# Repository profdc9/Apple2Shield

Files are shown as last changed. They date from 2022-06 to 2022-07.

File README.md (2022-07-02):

# Apple II Arduino Shield

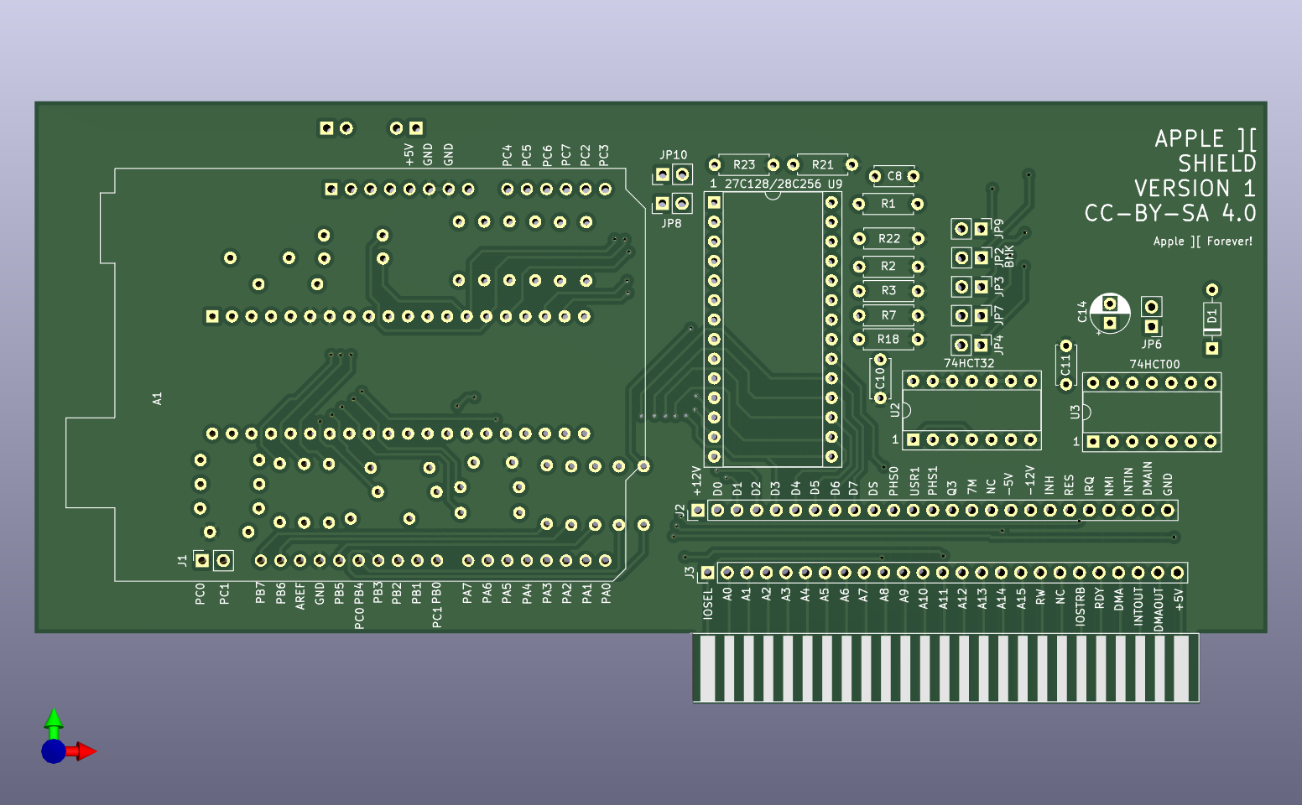
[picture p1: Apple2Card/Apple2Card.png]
Apple2Card


This is a simple card to interface an Apple II bus to an Arduino Uno or an Arduino Shield using the 82C55 interface.  If stackable headers are soldered into the interface card, an Arduino Uno may be mounted on the back of the card, and shields may be stacked on the front of the card.  This way an Arduino Shield may be used without an Arduino by the card by bit-banging it with the 82C55, or an Arduino may control the card.  There is also a ROM on the board that can contain your own firmware if you desire, and the hardware to flash it.  The design is derived from another project http://www.github.com/profdc9/Apple2Card

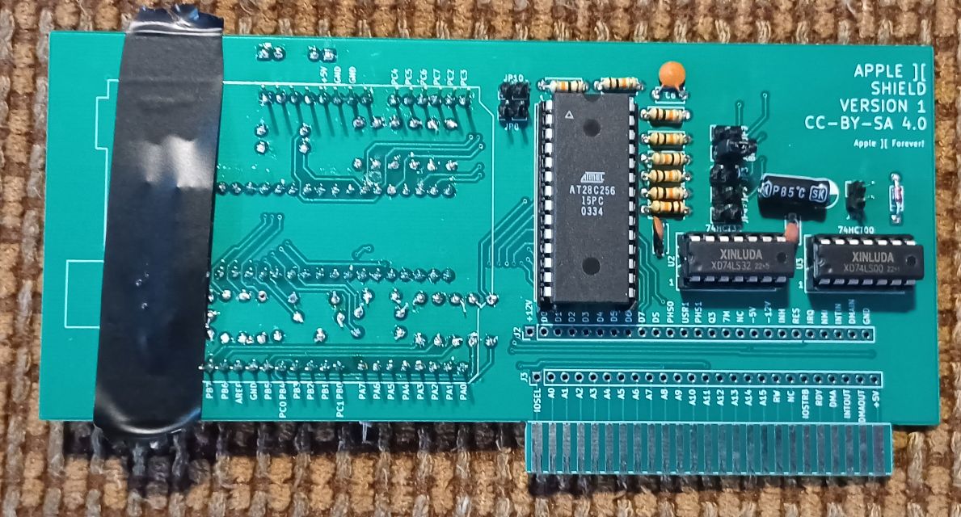
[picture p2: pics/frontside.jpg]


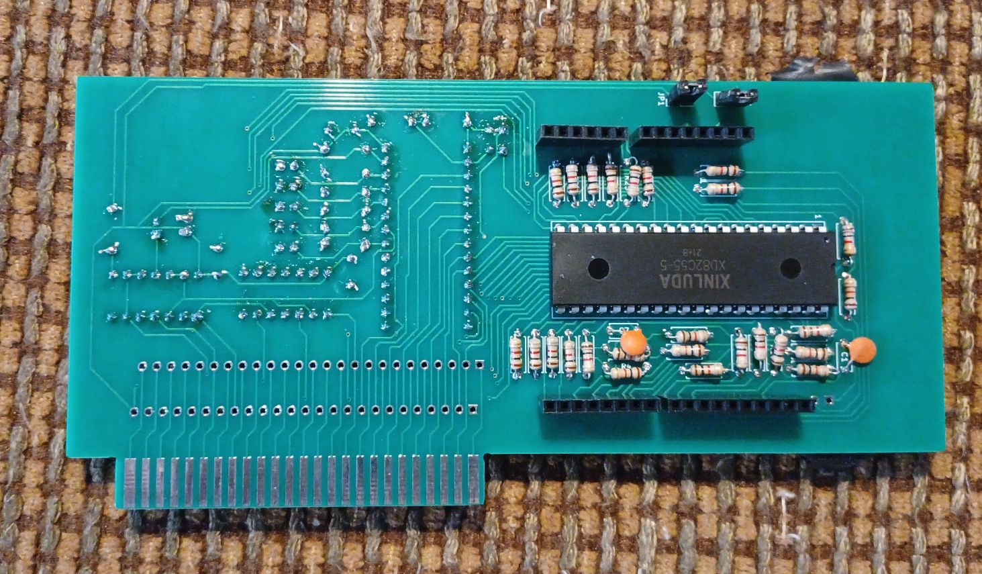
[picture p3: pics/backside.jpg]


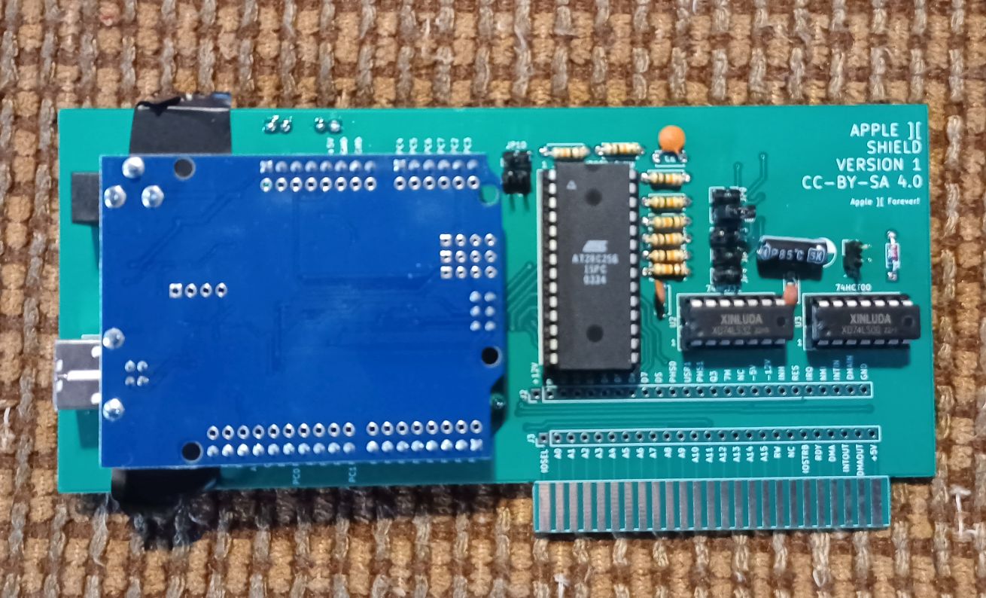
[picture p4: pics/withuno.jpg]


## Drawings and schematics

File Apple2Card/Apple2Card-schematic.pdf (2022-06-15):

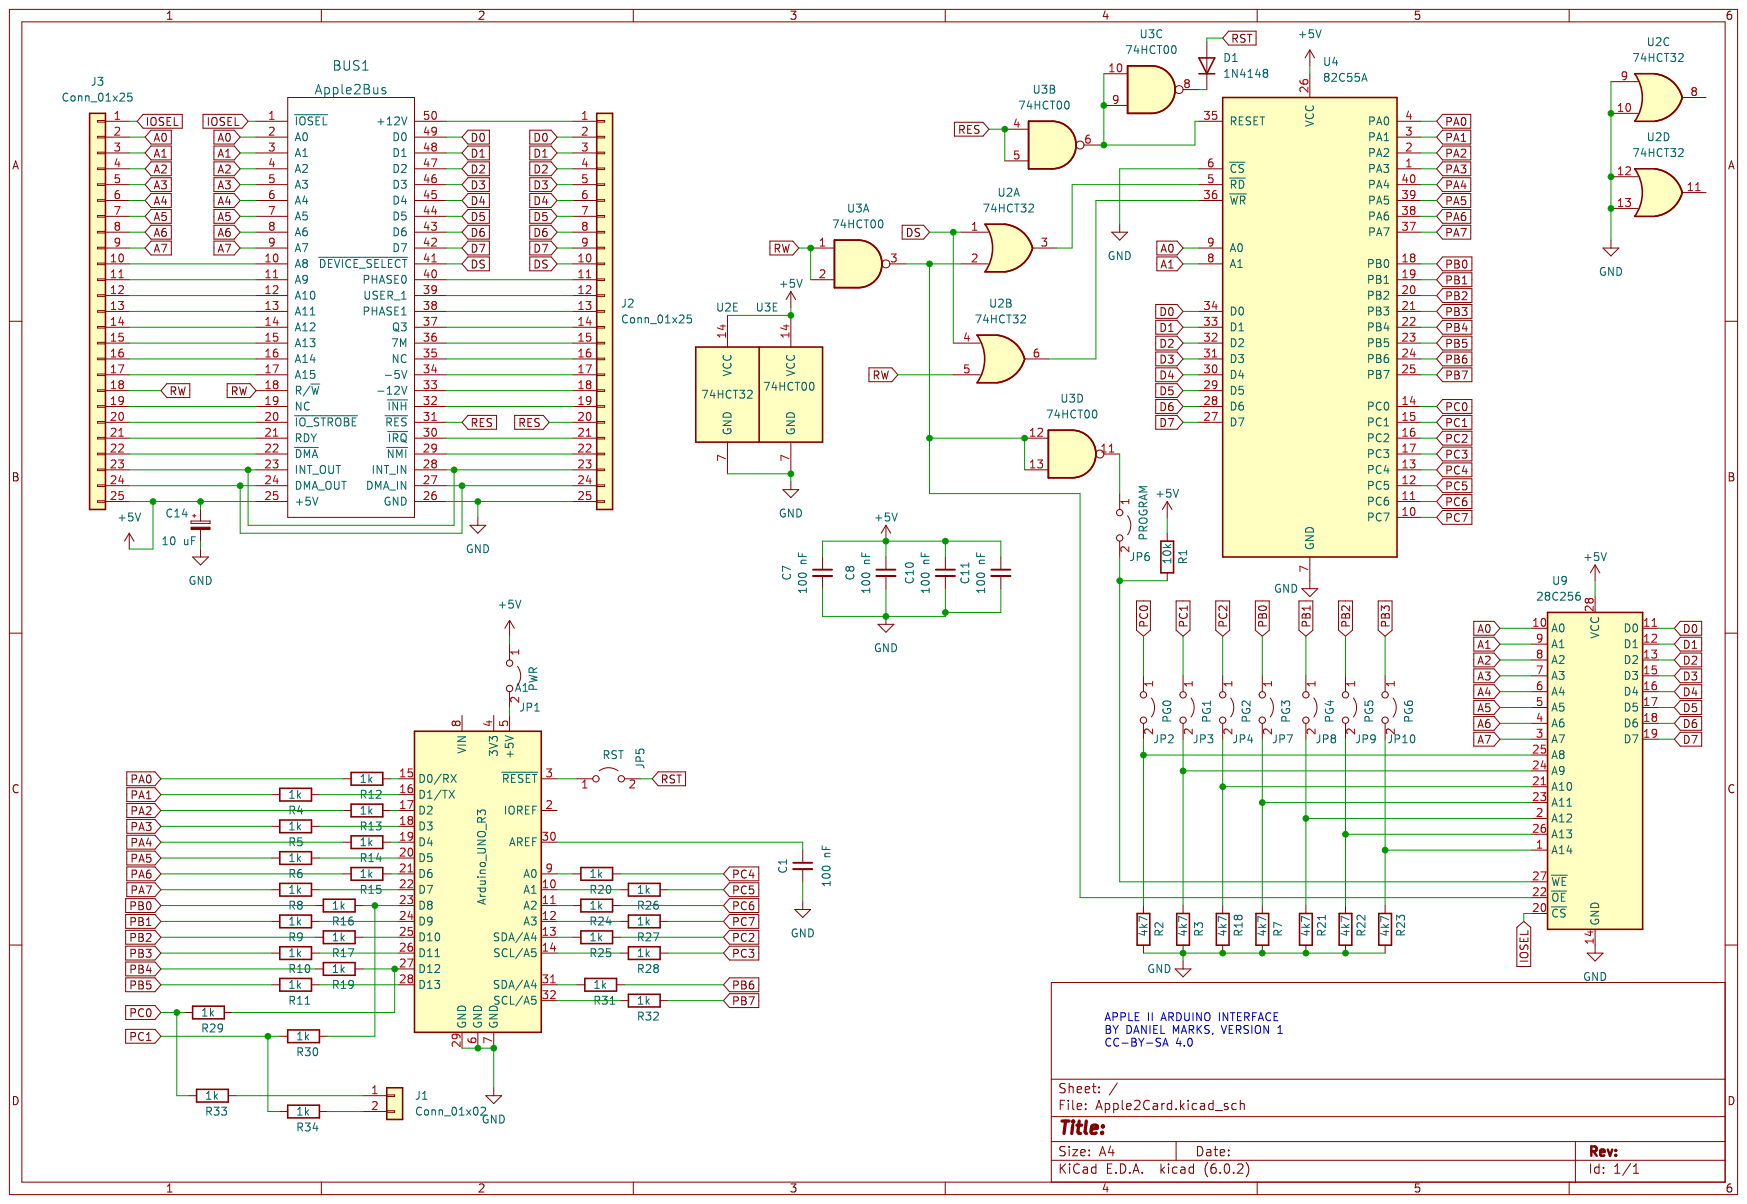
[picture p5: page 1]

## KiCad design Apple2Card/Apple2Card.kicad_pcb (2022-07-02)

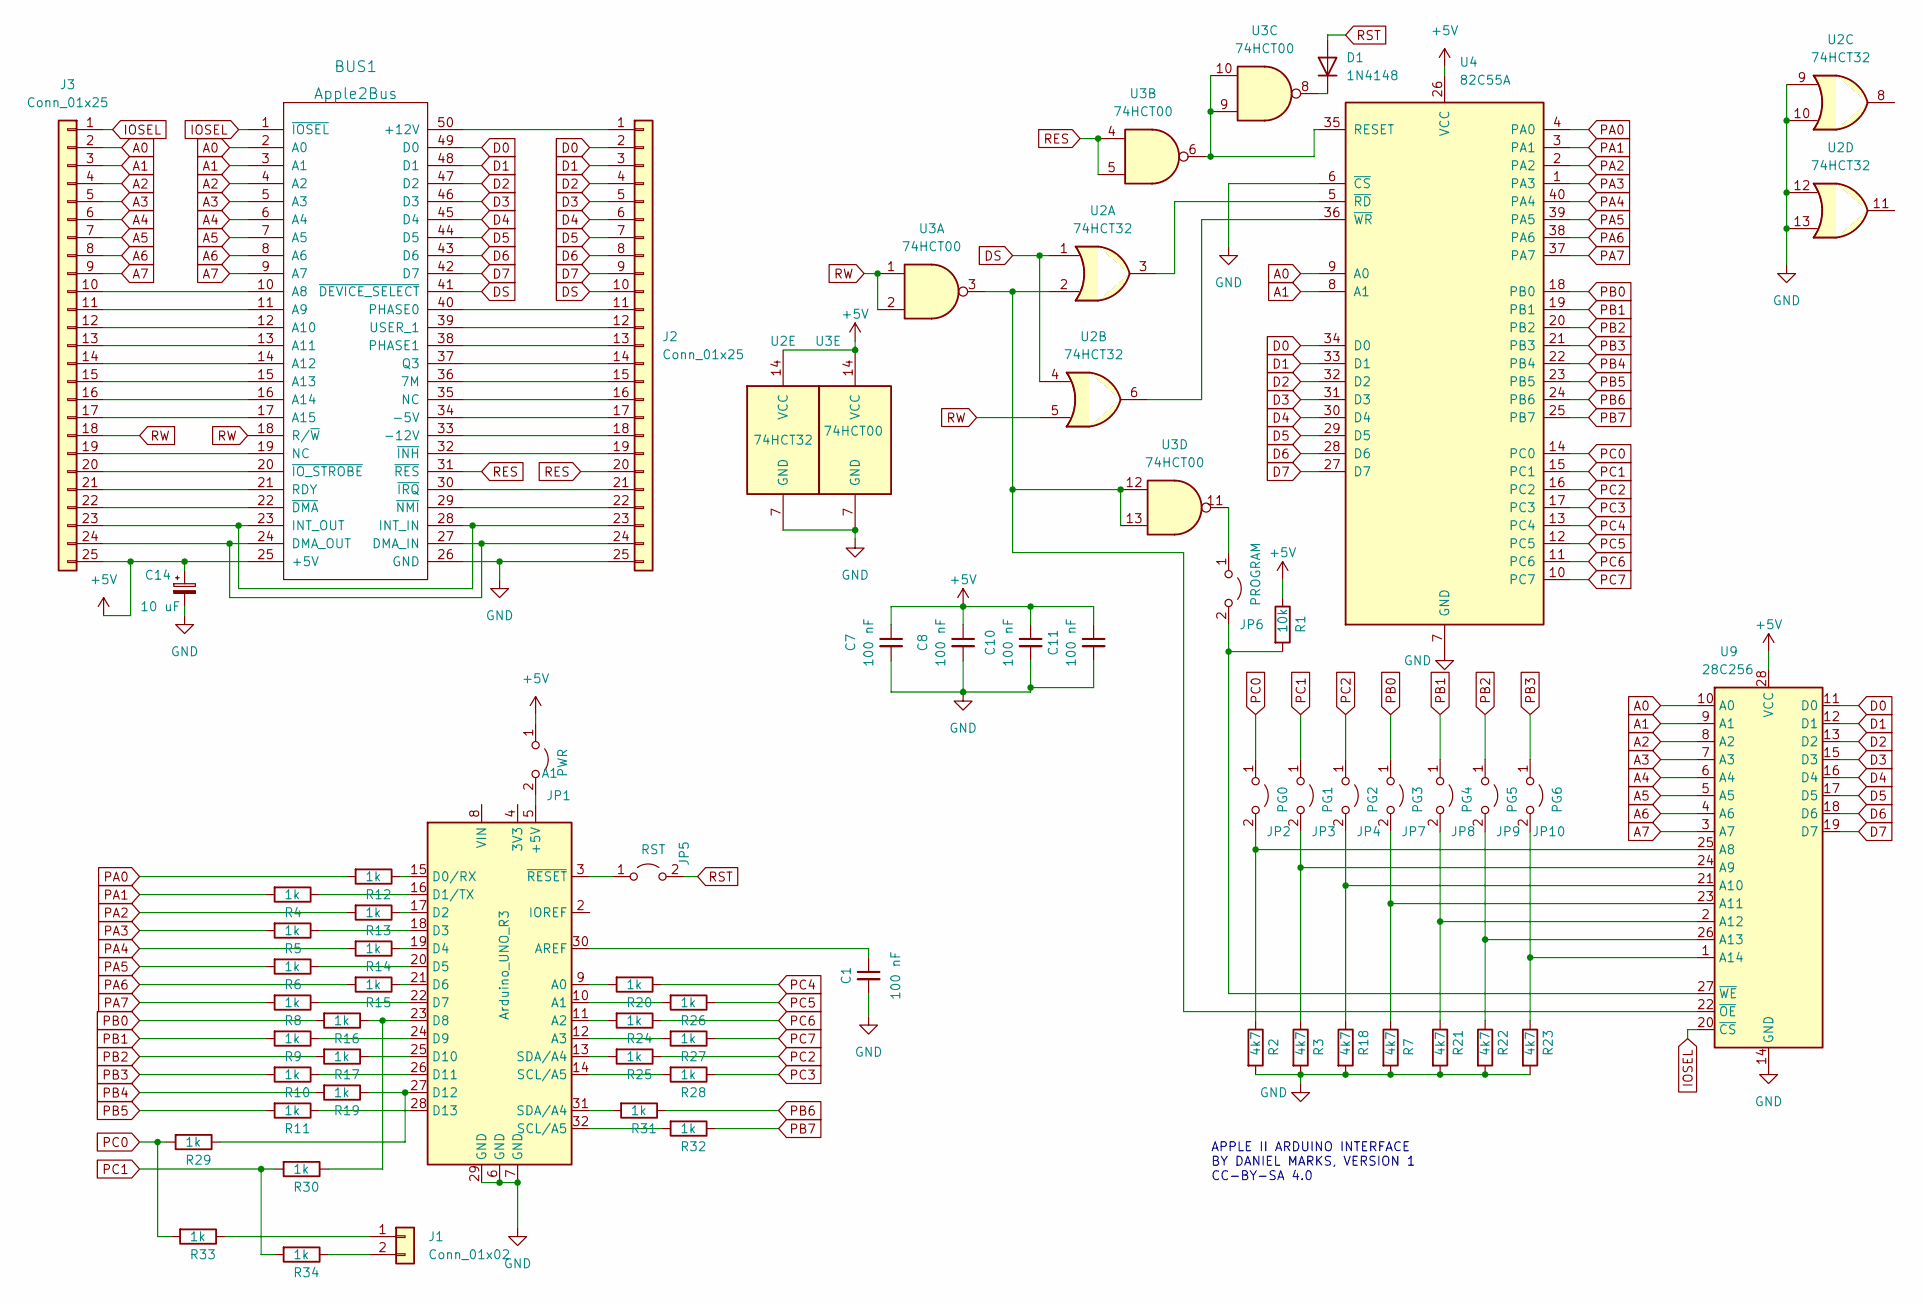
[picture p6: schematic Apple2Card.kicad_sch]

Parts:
A1: Arduino_UNO_R3
BUS1: Apple2Bus; Apple2Slot
C1, C7, C8, C10, C11: 100 nF; C_Disc_D5.0mm_W2.5mm_P5.00mm
C14: 10 uF; CP_Radial_D5.0mm_P2.50mm
D1: 1N4148; D_DO-35_SOD27_P7.62mm_Horizontal
J1: Conn_01x02; PinSocket_1x02_P2.54mm_Vertical
J2, J3: Conn_01x25; PinHeader_1x25_P2.54mm_Vertical
JP1: PWR; PinHeader_1x02_P2.54mm_Vertical
JP2: PG0; PinHeader_1x02_P2.54mm_Vertical
JP3: PG1; PinHeader_1x02_P2.54mm_Vertical
JP4: PG2; PinHeader_1x02_P2.54mm_Vertical
JP5: RST; PinHeader_1x02_P2.54mm_Vertical
JP6: PROGRAM; PinHeader_1x02_P2.54mm_Vertical
JP7: PG3; PinHeader_1x02_P2.54mm_Vertical
JP8: PG4; PinHeader_1x02_P2.54mm_Vertical
JP9: PG5; PinHeader_1x02_P2.54mm_Vertical
JP10: PG6; PinHeader_1x02_P2.54mm_Vertical
R1: 10k; R_Axial_DIN0207_L6.3mm_D2.5mm_P7.62mm_Horizontal
R2, R3, R7, R18, R21, R22, R23: 4k7; R_Axial_DIN0207_L6.3mm_D2.5mm_P7.62mm_Horizontal
R4, R5, R6, R8, R9, R10, R11, R12, R13, R14, R15, R16, R17, R19, R20, R24, R25, R26, R27, R28, R29, R30, R31, R32, R33, R34: 1k; R_Axial_DIN0207_L6.3mm_D2.5mm_P7.62mm_Horizontal
U2: 74HCT32; DIP-14_W7.62mm_Socket
U3: 74HCT00; DIP-14_W7.62mm_Socket
U4: 82C55A; DIP-40_W15.24mm_Socket
U9: 28C256; DIP-28_W15.24mm_Socket

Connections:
+5V: BUS1.25 (+5V), C7.1, C8.1, C10.1, C11.1, C14.1, J3.25, JP1.1 (A), R1.1, U2.14 (VCC), U3.14 (VCC), U4.26 (VCC), U9.28 (VCC)
A0: BUS1.2 (A0), J3.2, U4.9 (A0), U9.10 (A0)
A1: BUS1.3 (A1), J3.3, U4.8 (A1), U9.9 (A1)
A2: BUS1.4 (A2), J3.4, U9.8 (A2)
A3: BUS1.5 (A3), J3.5, U9.7 (A3)
A4: BUS1.6 (A4), J3.6, U9.6 (A4)
A5: BUS1.7 (A5), J3.7, U9.5 (A5)
A6: BUS1.8 (A6), J3.8, U9.4 (A6)
A7: BUS1.9 (A7), J3.9, U9.3 (A7)
D0: BUS1.49 (D0), J2.2, U4.34 (D0), U9.11 (D0)
D1: BUS1.48 (D1), J2.3, U4.33 (D1), U9.12 (D1)
D2: BUS1.47 (D2), J2.4, U4.32 (D2), U9.13 (D2)
D3: BUS1.46 (D3), J2.5, U4.31 (D3), U9.15 (D3)
D4: BUS1.45 (D4), J2.6, U4.30 (D4), U9.16 (D4)
D5: BUS1.44 (D5), J2.7, U4.29 (D5), U9.17 (D5)
D6: BUS1.43 (D6), J2.8, U4.28 (D6), U9.18 (D6)
D7: BUS1.42 (D7), J2.9, U4.27 (D7), U9.19 (D7)
DS: BUS1.41 (~DEVICE_SELECT), J2.10, U2.1, U2.4
GND: A1.6 (GND), A1.7 (GND), A1.29 (GND), BUS1.26 (GND), C1.2, C7.2, C8.2, C10.2, C11.2, C14.2, J2.25, R2.2, R3.2, R7.2, R18.2, R21.2, R22.2, R23.2, U2.7 (GND), U2.9, U2.10, U2.12, U2.13, U3.7 (GND), U4.6 (~CS), U4.7 (GND), U9.14 (GND)
IOSEL: BUS1.1 (~IOSEL), J3.1, U9.20 (~CS)
unnamed: A1.3 (~RESET), JP5.1 (A)
unnamed: A1.5 (+5V), JP1.2 (B)
unnamed: A1.9 (A0), R20.2
unnamed: A1.10 (A1), R26.2
unnamed: A1.11 (A2), R24.2
unnamed: A1.12 (A3), R27.2
unnamed: A1.13 (SDA/A4), R25.2
unnamed: A1.14 (SCL/A5), R28.2
unnamed: A1.15 (D0/RX), R12.1
unnamed: A1.16 (D1/TX), R4.1
unnamed: A1.17 (D2), R13.1
unnamed: A1.18 (D3), R5.1
unnamed: A1.19 (D4), R14.1
unnamed: A1.20 (D5), R6.1
unnamed: A1.21 (D6), R15.1
unnamed: A1.22 (D7), R8.1
unnamed: A1.23 (D8), R16.1, R30.1
unnamed: A1.24 (D9), R9.1
unnamed: A1.25 (D10), R17.1
unnamed: A1.26 (D11), R10.1
unnamed: A1.27 (D12), R19.1, R29.1
unnamed: A1.28 (D13), R11.1
unnamed: A1.30 (AREF), C1.1
unnamed: A1.31 (SDA/A4), R31.2
unnamed: A1.32 (SCL/A5), R32.2
unnamed: BUS1.10 (A8), J3.10
unnamed: BUS1.11 (A9), J3.11
unnamed: BUS1.12 (A10), J3.12
unnamed: BUS1.13 (A11), J3.13
unnamed: BUS1.14 (A12), J3.14
unnamed: BUS1.15 (A13), J3.15
unnamed: BUS1.16 (A14), J3.16
unnamed: BUS1.17 (A15), J3.17
unnamed: BUS1.19 (NC), J3.19
unnamed: BUS1.20 (~IO_STROBE), J3.20
unnamed: BUS1.21 (RDY), J3.21
unnamed: BUS1.22 (~DMA), J3.22
unnamed: BUS1.23 (INT_OUT), BUS1.28 (INT_IN), J2.23, J3.23
unnamed: BUS1.24 (DMA_OUT), BUS1.27 (DMA_IN), J2.24, J3.24
unnamed: BUS1.29 (~NMI), J2.22
unnamed: BUS1.30 (~IRQ), J2.21
unnamed: BUS1.32 (~INH), J2.19
unnamed: BUS1.33 (-12V), J2.18
unnamed: BUS1.34 (-5V), J2.17
unnamed: BUS1.35 (NC), J2.16
unnamed: BUS1.36 (7M), J2.15
unnamed: BUS1.37 (Q3), J2.14
unnamed: BUS1.38 (PHASE1), J2.13
unnamed: BUS1.39 (USER_1), J2.12
unnamed: BUS1.40 (PHASE0), J2.11
unnamed: BUS1.50 (+12V), J2.1
unnamed: D1.1 (K), U3.8
unnamed: J1.1, R33.1
unnamed: J1.2, R34.1
unnamed: JP2.2 (B), R2.1, U9.25 (A8)
unnamed: JP3.2 (B), R3.1, U9.24 (A9)
unnamed: JP4.2 (B), R18.1, U9.21 (A10)
unnamed: JP6.1 (A), U3.11
unnamed: JP6.2 (B), R1.2, U9.27 (~WE)
unnamed: JP7.2 (B), R7.1, U9.23 (A11)
unnamed: JP8.2 (B), R21.1, U9.2 (A12)
unnamed: JP9.2 (B), R22.1, U9.26 (A13)
unnamed: JP10.2 (B), R23.1, U9.1 (A14)
unnamed: U2.2, U3.3, U3.12, U3.13, U9.22 (~OE)
unnamed: U2.3, U4.5 (~RD)
unnamed: U2.6, U4.36 (~WR)
unnamed: U3.6, U3.9, U3.10, U4.35 (RESET)
PA0: R12.2, U4.4 (PA0)
PA1: R4.2, U4.3 (PA1)
PA2: R13.2, U4.2 (PA2)
PA3: R5.2, U4.1 (PA3)
PA4: R14.2, U4.40 (PA4)
PA5: R6.2, U4.39 (PA5)
PA6: R15.2, U4.38 (PA6)
PA7: R8.2, U4.37 (PA7)
PB0: JP7.1 (A), R16.2, U4.18 (PB0)
PB1: JP8.1 (A), R9.2, U4.19 (PB1)
PB2: JP9.1 (A), R17.2, U4.20 (PB2)
PB3: JP10.1 (A), R10.2, U4.21 (PB3)
PB4: R19.2, U4.22 (PB4)
PB5: R11.2, U4.23 (PB5)
PB6: R31.1, U4.24 (PB6)
PB7: R32.1, U4.25 (PB7)
PC0: JP2.1 (A), R29.2, R33.2, U4.14 (PC0)
PC1: JP3.1 (A), R30.2, R34.2, U4.15 (PC1)
PC2: JP4.1 (A), R25.1, U4.16 (PC2)
PC3: R28.1, U4.17 (PC3)
PC4: R20.1, U4.13 (PC4)
PC5: R26.1, U4.12 (PC5)
PC6: R24.1, U4.11 (PC6)
PC7: R27.1, U4.10 (PC7)
RES: BUS1.31 (~RES), J2.20, U3.4, U3.5
RST: D1.2 (A), JP5.2 (B)
RW: BUS1.18 (R/~W), J3.18, U2.5, U3.1, U3.2

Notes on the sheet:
APPLE II ARDUINO INTERFACE BY DANIEL MARKS, VERSION 1 CC-BY-SA 4.0

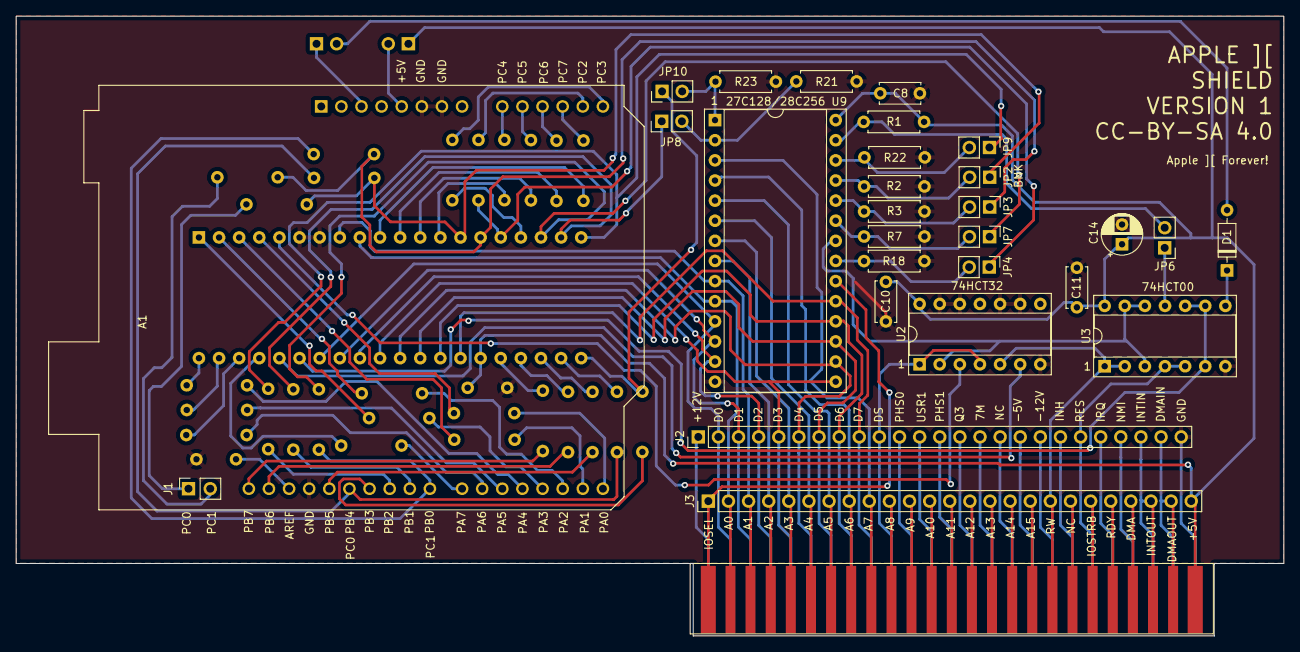
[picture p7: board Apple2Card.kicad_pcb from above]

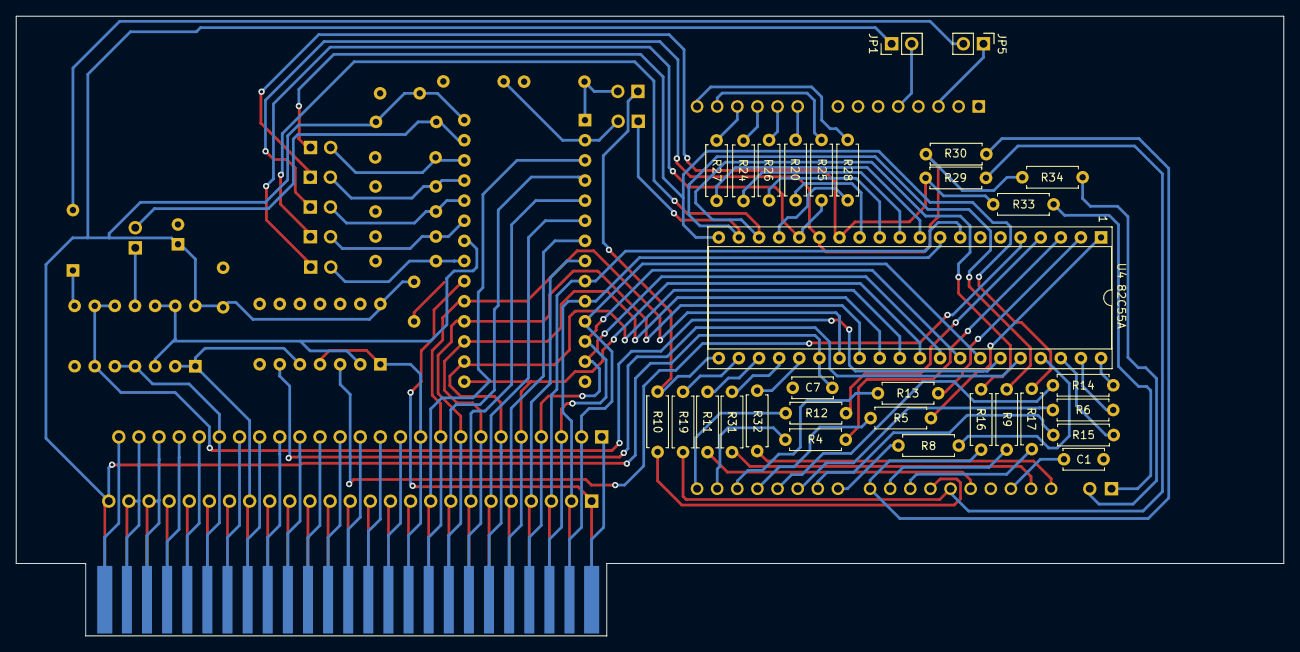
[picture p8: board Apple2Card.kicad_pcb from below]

Board: 2 copper layers, 160.0 x 78.2 mm, 60 parts (31 on the bottom side), 114 nets.

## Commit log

2022-06-15 JLCPCB Order 2022-06-15
    [Apple2Card-B_Cu.gbr, Apple2Card-B_Mask.gbr, Apple2Card-B_Silkscreen.gbr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]
2022-07-02 Fixed layout a bit, added pictures
    [Apple2Card-B_Cu.gbr, Apple2Card-B_Mask.gbr, Apple2Card-B_Silkscreen.gbr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]
